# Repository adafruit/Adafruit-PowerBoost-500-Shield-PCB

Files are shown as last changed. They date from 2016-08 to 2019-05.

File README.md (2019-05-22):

## Adafruit PowerBoost 500 Shield PCB
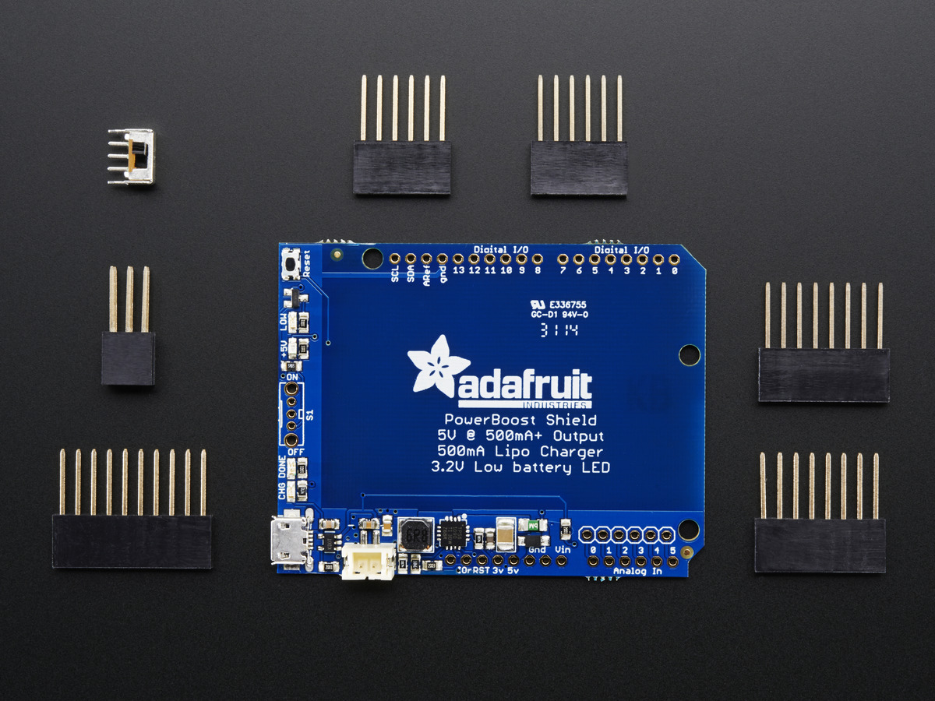
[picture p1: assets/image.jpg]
<a href="http://www.adafruit.com/products/2078"><br/>
Click here to purchase one from the Adafruit shop</a>

The PowerBoost shield! This stackable shield goes onto your Arduino and provides a slim rechargeable power pack, with a built in battery charger as well as DC/DC booster.

Compatible with Adafruit Metro, Arduino Uno, Duemilanove, Mega, Leonardo and Due - basically any Arduino-pinout-shaped Arduino as only the GND and 5V pins are used. You can stack shields on top, or stack the PowerBoost on top. Please note that the powerboost does not pass through the ICSP headers (the battery is in the way) so if your stacking shield uses ICSP for data transfer (like the Ethernet Shield), you'll need to stack the PowerBoost above it!

The PowerBoost shield can run off of any Lithium Ion or Lithium Polymer battery (3.7/4.2V kind) but we suggest our 1200mAh capacity  or 2000mAh capacity batteries, both of which fits very nicely in the empty space of the shield. Plug in the battery and recharge it via the microUSB jack. When you're ready to go, just unplug the Arduino from USB or the wall adapter and it will automatically switch over to shield power. Use only Lipoly batteries with protection circuitry!

The onboard boost converter can provide at least 500mA current, and can peak at 1A. There's an onboard fuse to protect against higher current draws which could damage the boost converter or battery. The boost converter can be damaged by high current spikes and is not recommended for driving motors or robots where the stall current can cause high current spikes

PCB files for the Adafruit PowerBoost 500 Shield. The format is EagleCAD schematic and board layout
- https://www.adafruit.com/product/2078

### License

Adafruit invests time and resources providing this open source design, please support Adafruit and open-source hardware by purchasing products from [Adafruit](https://www.adafruit.com)!

All text above must be included in any redistribution

Designed by Limor Fried/Ladyada for Adafruit Industries.
Creative Commons Attribution/Share-Alike, all text above must be included in any redistribution. 
See license.txt for additional information.

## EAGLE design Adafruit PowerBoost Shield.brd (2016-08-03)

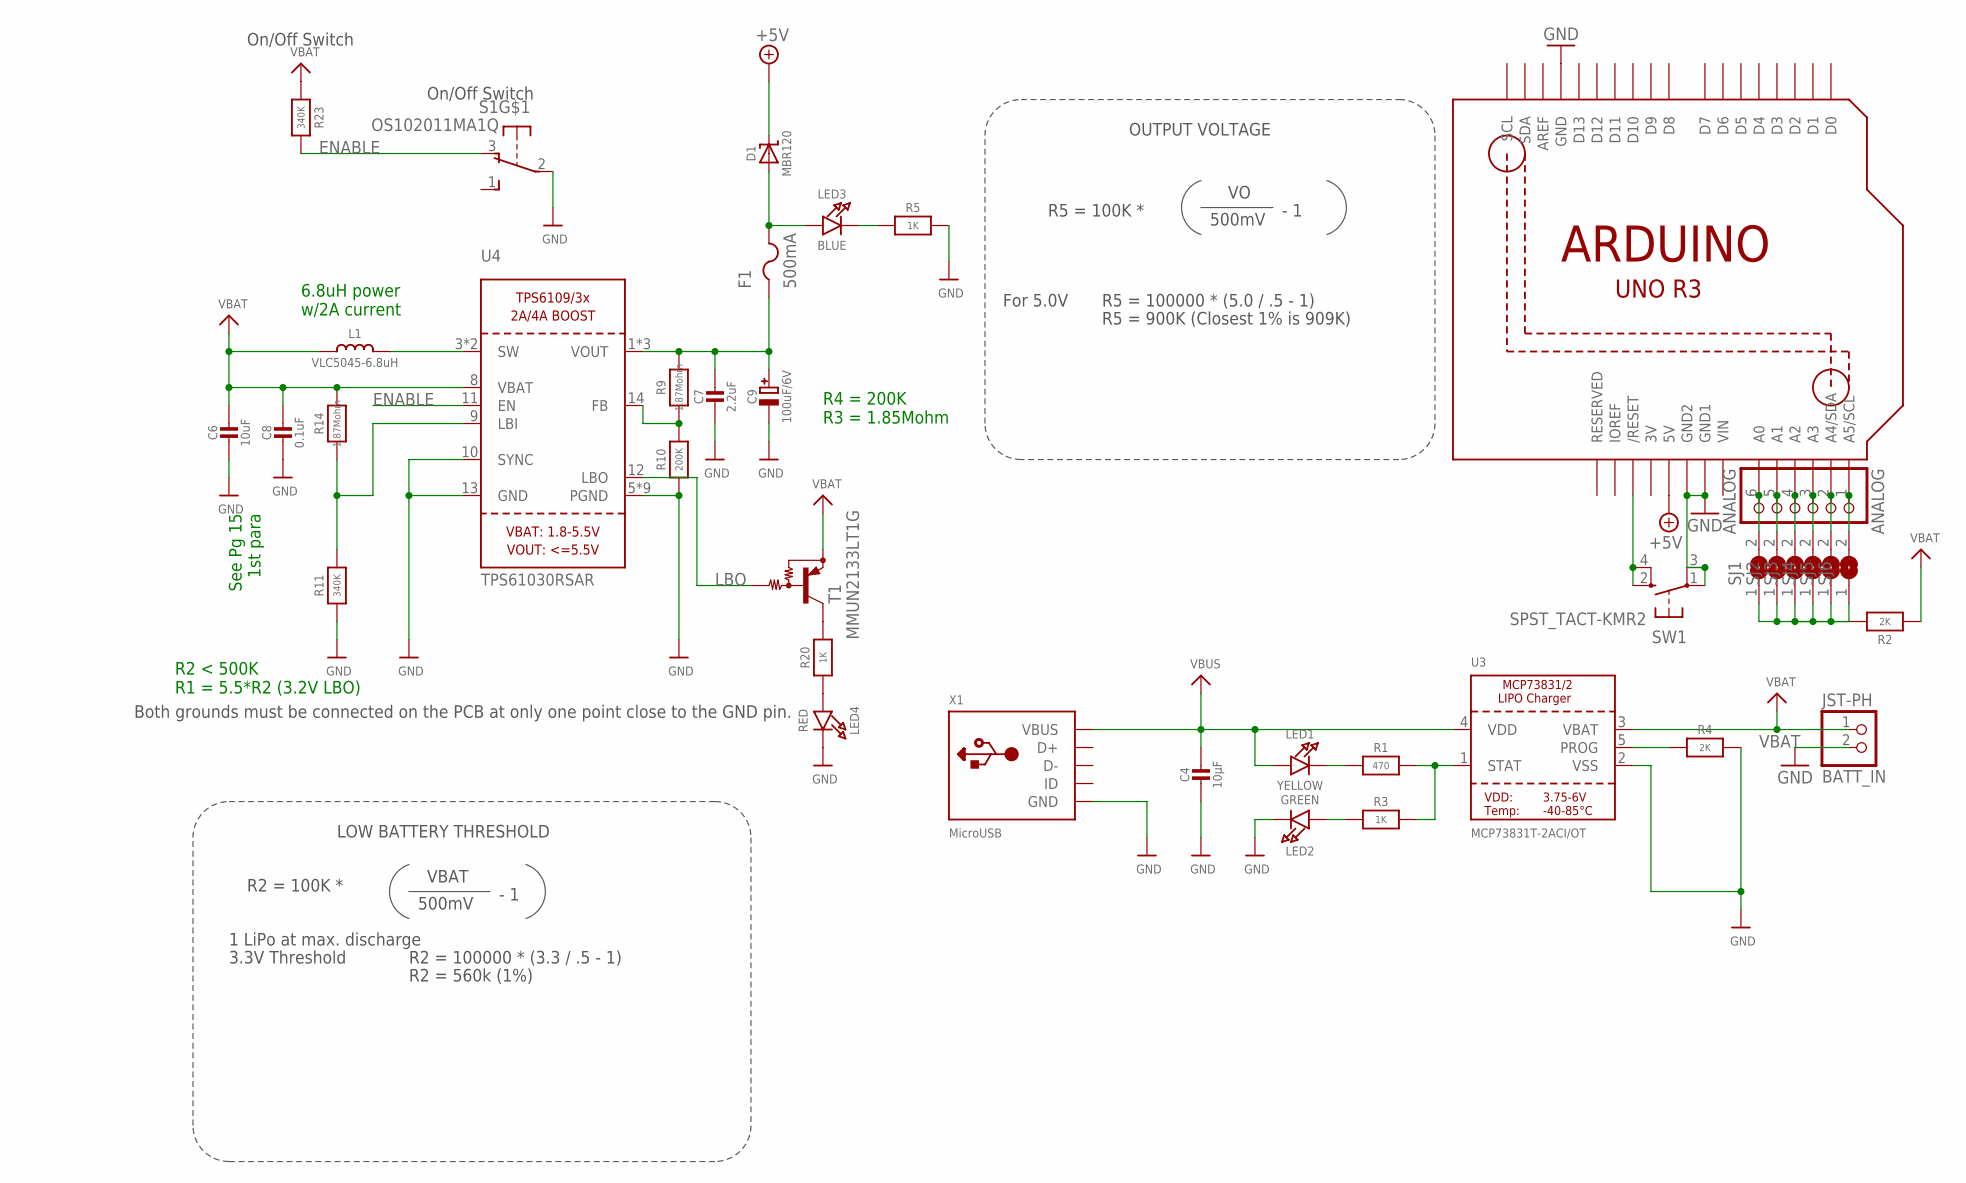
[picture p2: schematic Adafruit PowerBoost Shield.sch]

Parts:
ANALOG: ANALOG; 1X06
BATT_IN: JST-PH; JST-PH-2-SMT
C4: 10µF; 0805-NO
C6: 10uF; 0805-NO
C7: 2.2uF; 0805-NO
C8: 0.1uF; 0805-NO
C9: 100uF/6V; EIA3528-21/B-R
D1: MBR120; SOD-123
F1: 500mA; R1206
L1: VLC5045-6.8uH; INDUCTOR_5X5MM_TDK_VLC5045
LED1: YELLOW; CHIPLED_0805_NOOUTLINE
LED2: GREEN; CHIPLED_0805_NOOUTLINE
LED3: BLUE; CHIPLED_0805_NOOUTLINE
LED4: RED; CHIPLED_0805_NOOUTLINE
R1: 470; 0805-NO
R2, R4: 2K; 0805-NO
R3, R5, R20: 1K; 0805-NO
R9, R14: 1.87Mohm; 0805-NO
R10: 200K; 0805-NO
R11, R23: 340K; 0805-NO
S1: OS102011MA1Q
SJ1, SJ2, SJ3, SJ4, SJ5, SJ6: SOLDERJUMPER; SOLDERJUMPER_ARROW_NOPASTE
SW1: SPST_TACT-KMR2; KMR2
T1: MMUN2133LT1G; SC59-BEC
U2: ARDUINOR3-NOSILK
U3: MCP73831T-2ACI/OT; SOT23-5
U4: TPS61030RSAR; PVQFN-16
U$3, U$4: FIDUCIAL; FIDUCIAL_1MM
X1: MicroUSB; 4UCONN_20329

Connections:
3V: U2.3V
+5V: D1.C, U2.5V
A0: ANALOG.6, SJ1.2, U2.A0
A1: ANALOG.5, SJ2.2, U2.A1
A2: ANALOG.4, SJ3.2, U2.A2
A3: ANALOG.3, SJ4.2, U2.A3
A4: ANALOG.2, SJ5.2, U2.A4 (A4/SDA)
A5: ANALOG.1, SJ6.2, U2.A5 (A5/SCL)
ENABLE: R23.2, S1.3 (O), U4.11 (EN)
FB: R9.1, R10.2, U4.14 (FB)
GND: BATT_IN.2 (1), C4.2, C6.2, C7.2, C8.2, C9.-, LED2.C, LED4.C, R4.2, R5.2, R10.1, R11.1, S1.2, SW1.1, SW1.3 (P1), U2.GND, U2.GND1, U2.GND2, U3.2 (VSS), U4.5 (PGND), U4.6 (PGND), U4.7 (PGND), U4.10 (SYNC), U4.13 (GND), U4.P$18 (PGND), U4.P$19 (PGND), U4.P$20 (PGND), U4.P$21 (PGND), U4.P$22 (PGND), U4.THERMAL (PGND), X1.BASE@1 (GND), X1.BASE@2 (GND), X1.GND, X1.SPRT@1 (GND), X1.SPRT@2 (GND), X1.SPRT@3 (GND), X1.SPRT@4 (GND)
LBI: R11.2, R14.1, U4.9 (LBI)
LBO: T1.B, U4.12 (LBO)
unnamed: R2.2, SJ1.1, SJ2.1, SJ3.1, SJ4.1, SJ5.1, SJ6.1
unnamed: LED1.C, R1.1
unnamed: R1.2, R3.2, U3.1 (STAT)
unnamed: L1.P$2 (2), U4.3 (SW), U4.4 (SW)
unnamed: R4.1, U3.5 (PROG)
unnamed: LED2.A, R3.1
unnamed: LED3.C, R5.1
unnamed: LED4.A, R20.1
unnamed: R20.2, T1.C
unnamed: D1.A, F1.2, LED3.A
RESET: SW1.2 (S), SW1.4 (S1), U2.RESET (/RESET)
VBAT: BATT_IN.1 (2), C6.1, C8.1, L1.P$1 (1), R2.1, R14.2, R23.1, T1.E, U3.3 (VBAT), U4.8 (VBAT)
VBUS: C4.1, LED1.A, U3.4 (VDD), X1.VBUS
VIN: U2.VIN
VOUT: C7.1, C9.+, F1.1, R9.2, U4.1 (VOUT), U4.15 (VOUT), U4.16 (VOUT)

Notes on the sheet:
R2 = 100K *
VBAT
500mV
- 1
3.3V Threshold
R2 = 100000 * (3.3 / .5 - 1)
LOW BATTERY THRESHOLD
OUTPUT VOLTAGE
R5 = 100K *
For 5.0V
R5 = 100000 * (5.0 / .5 - 1)
R5 = 900K (Closest 1% is 909K)
1 LiPo at max. discharge
On/Off Switch
R2 = 560k (1%)
Both grounds must be connected on the PCB at only one point close to the GND pin.
See Pg 15 1st para
6.8uH power w/2A current
R2 < 500K R1 = 5.5*R2 (3.2V LBO)
R4 = 200K R3 = 1.85Mohm

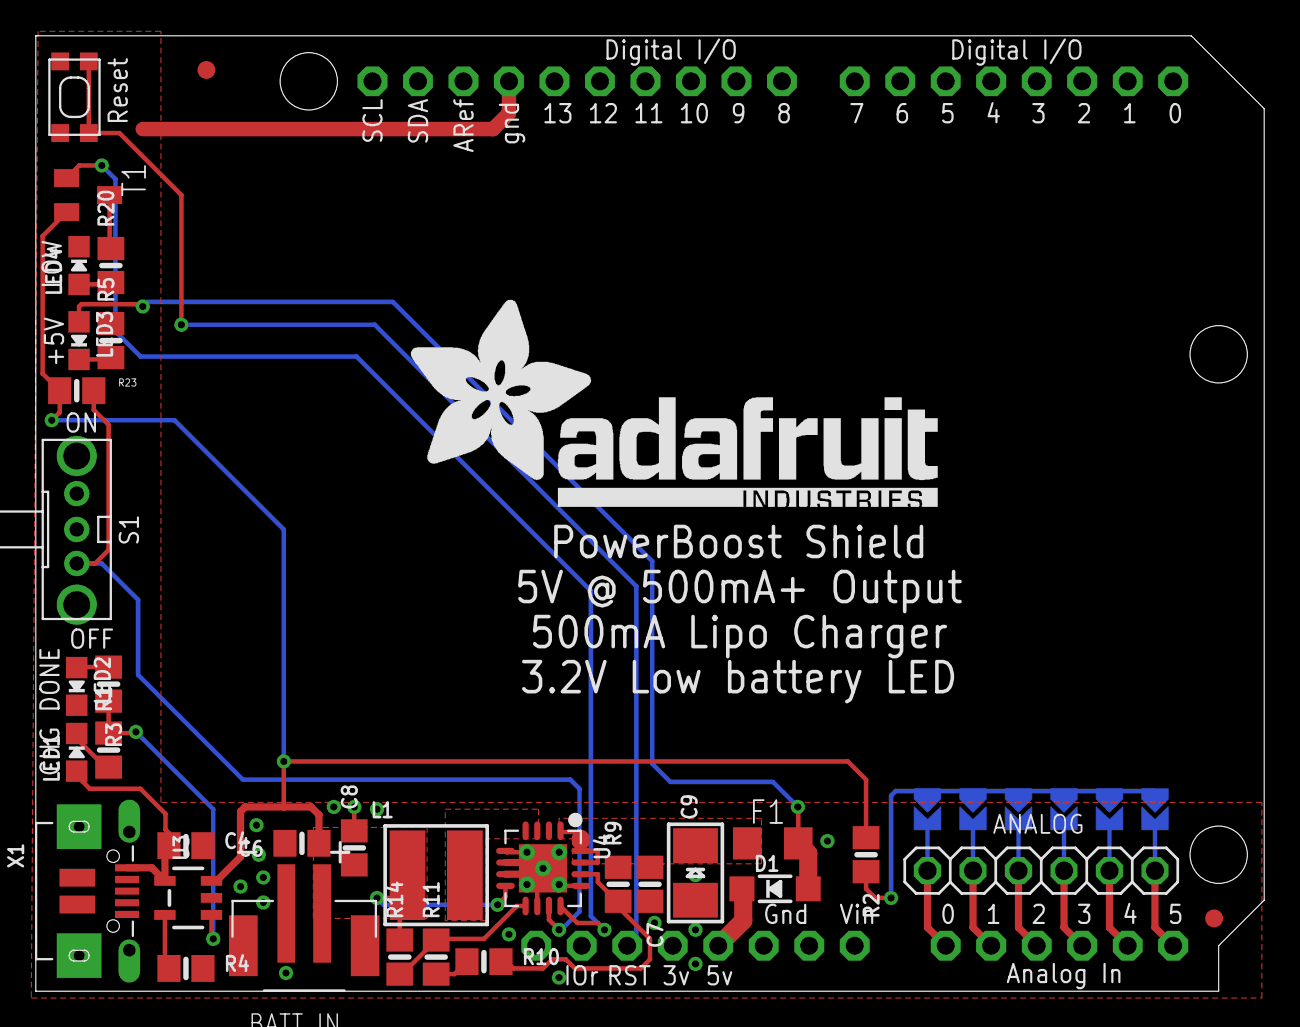
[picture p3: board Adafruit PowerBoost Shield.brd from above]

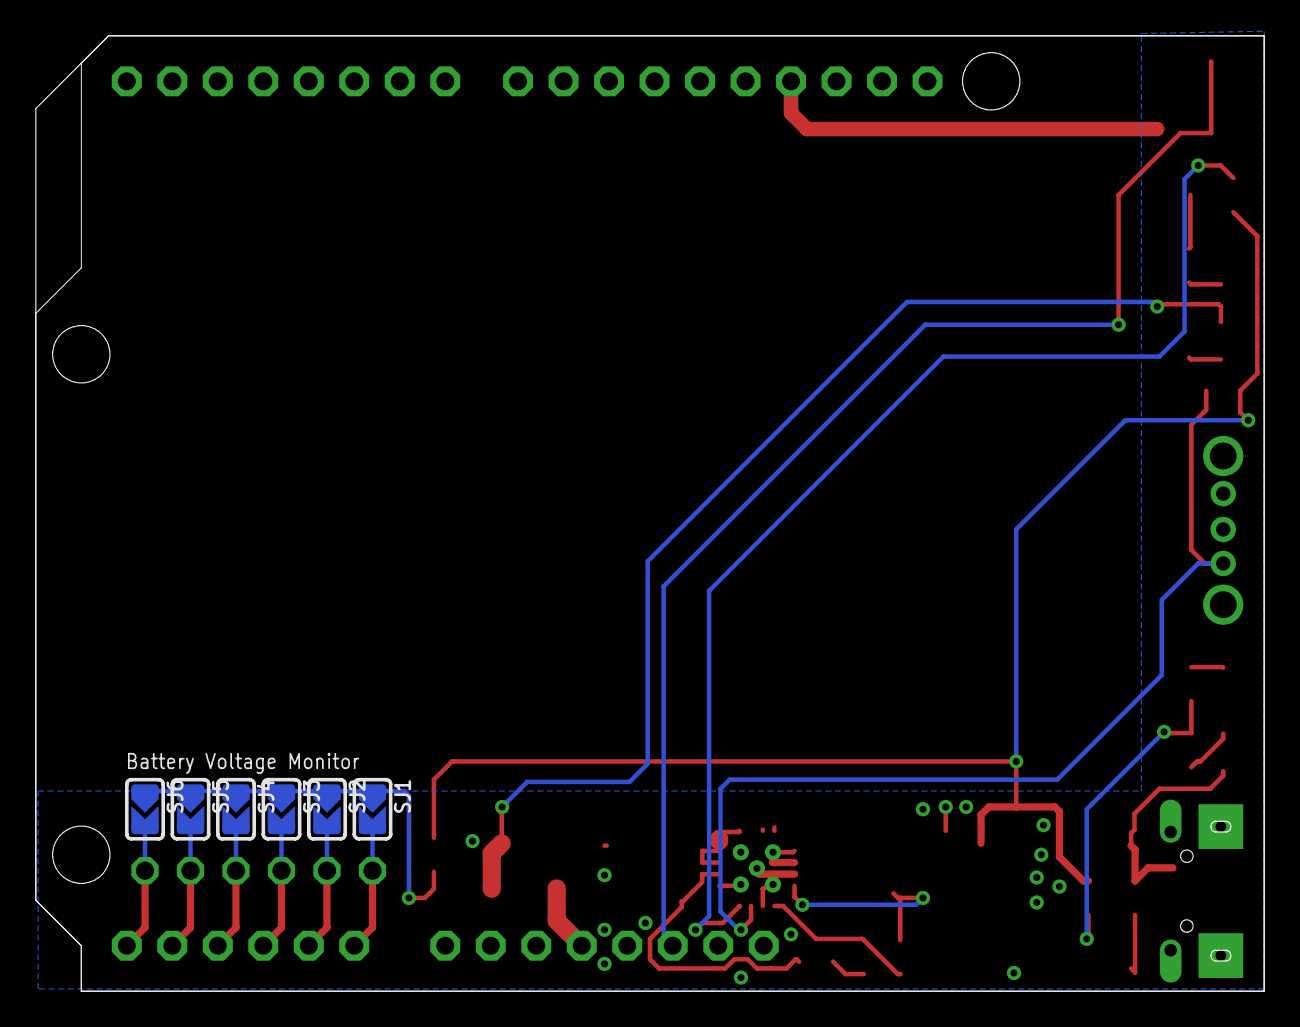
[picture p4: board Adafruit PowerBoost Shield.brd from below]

Board: 2 copper layers, 68.6 x 53.3 mm, 41 parts (6 on the bottom side), 26 nets.

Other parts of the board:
U$6: ADAFRUIT_TEXT_30MM
